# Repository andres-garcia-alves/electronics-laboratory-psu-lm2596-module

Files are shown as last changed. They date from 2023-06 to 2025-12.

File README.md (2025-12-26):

# Laboratory Power Supply Unit - LM2596 Module

Electronic adjustable laboratory power supply unit based on LM2596 DC-DC Step-Down module.  
Output 1.25-30V, max 2A, with current limitation feature.  

Based on videos (spanish):  
- [Control de Corriente para Fuente DC-DC LM2596](https://www.youtube.com/watch?v=ucfL-aOuTAA) from [KrissElectronics](https://www.youtube.com/@KrissElectronics) YouTube channel.
- [Fuente DC-DC LM2596, Control Externo Feedback](https://www.youtube.com/watch?v=mXjmIwHC1IA) from [Electgpl](https://www.youtube.com/@electgpl) YouTube channel.
- [Control de Corriente para DC-DC con LM2596, CC/CV con LM358](https://www.youtube.com/watch?v=a19zc0bWBYk) from [Electgpl](https://www.youtube.com/@electgpl) YouTube channel.

&nbsp;

This project use the following electronic components:
- 1 x LM2596 DC-DC Step-Down module (with current limitation).
- 1 x Voltimeter+Amperimeter DSN-VC288.
- 2 x Potenciometers B10K (lineal)
- 1 x Resistor 2.2ohm 15w.
- 2 x Borniers.
- 2 x 3 pins connectors.
- 1 x DC Jack female connector.

&nbsp;

### Screenshots

| Diagram - Schematics | Diagram - PCB |
|---|---|
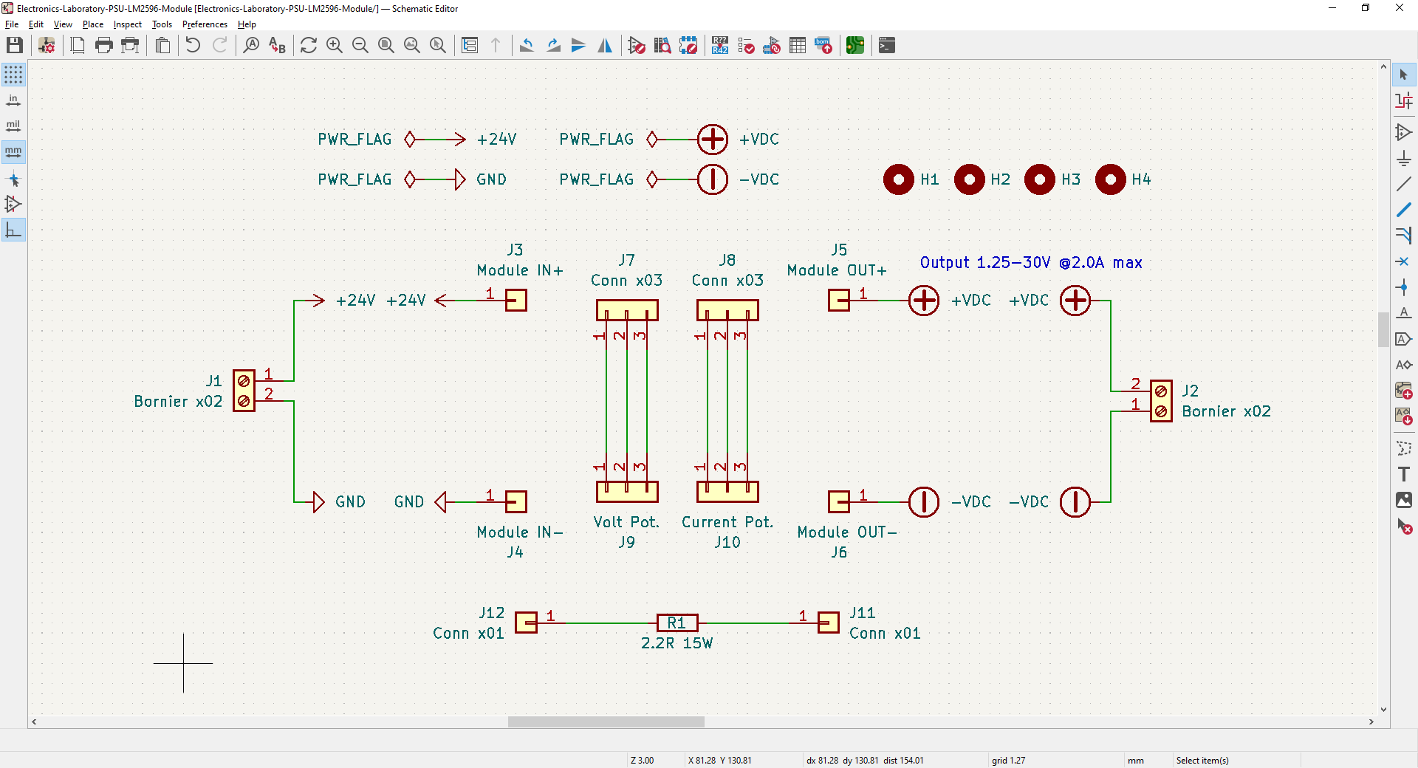
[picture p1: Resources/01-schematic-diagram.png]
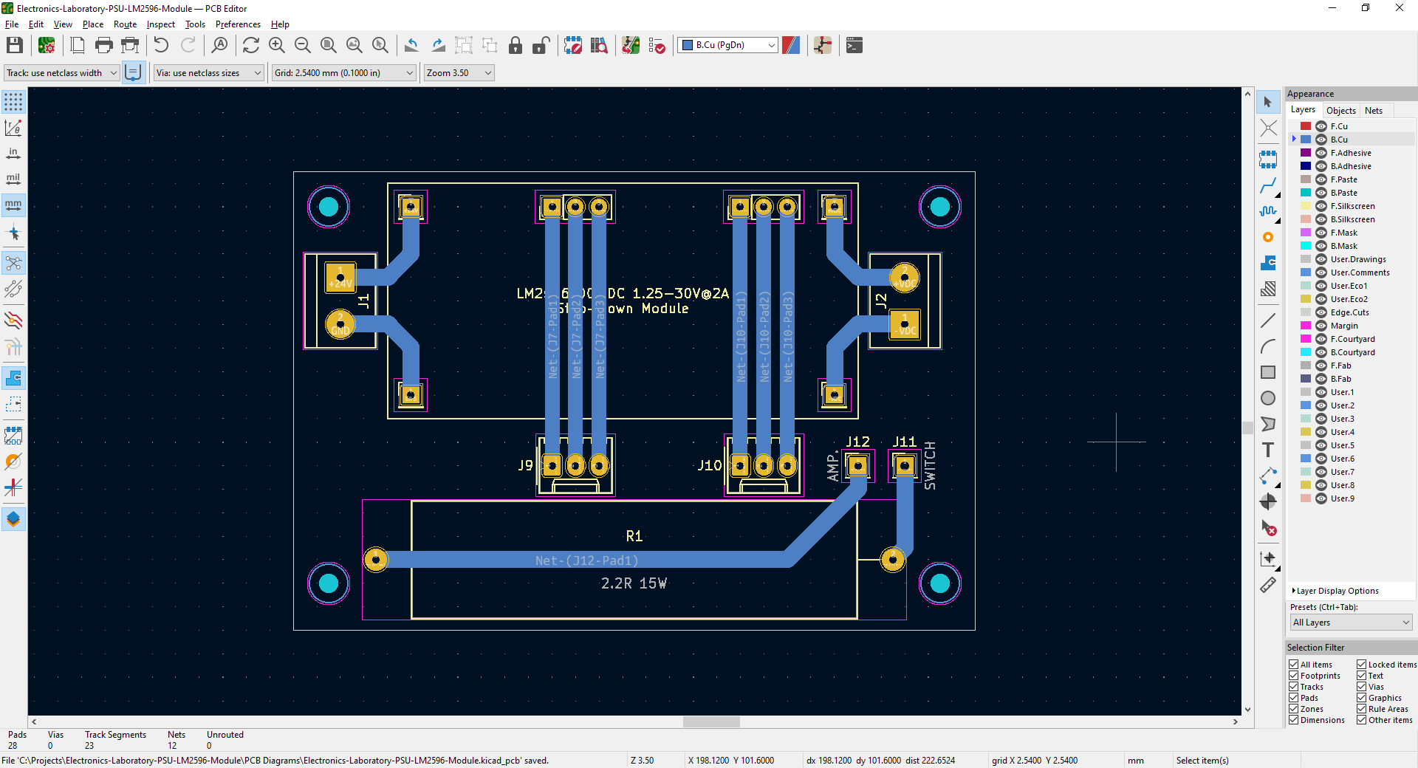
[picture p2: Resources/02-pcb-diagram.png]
|  |  |

| Diagram - PCB Render | Diagram - PCB Render |
|---|---|
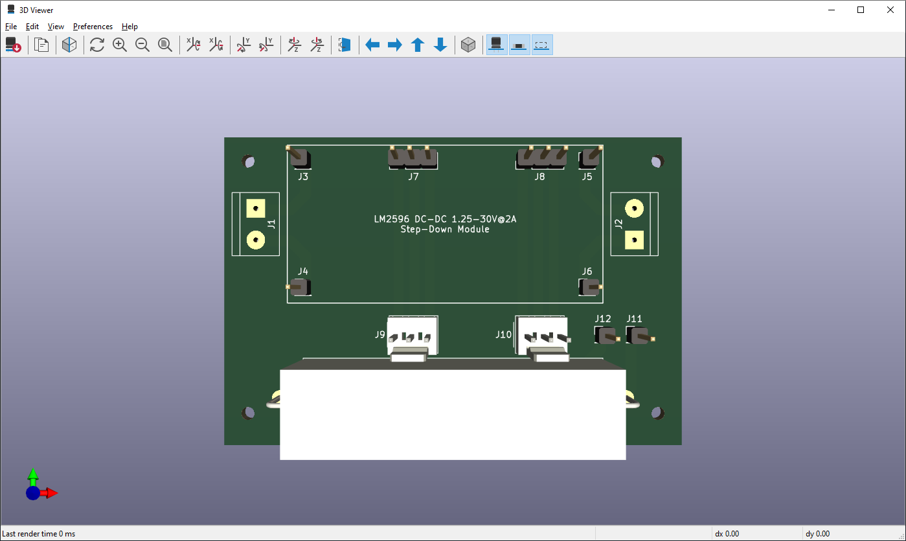
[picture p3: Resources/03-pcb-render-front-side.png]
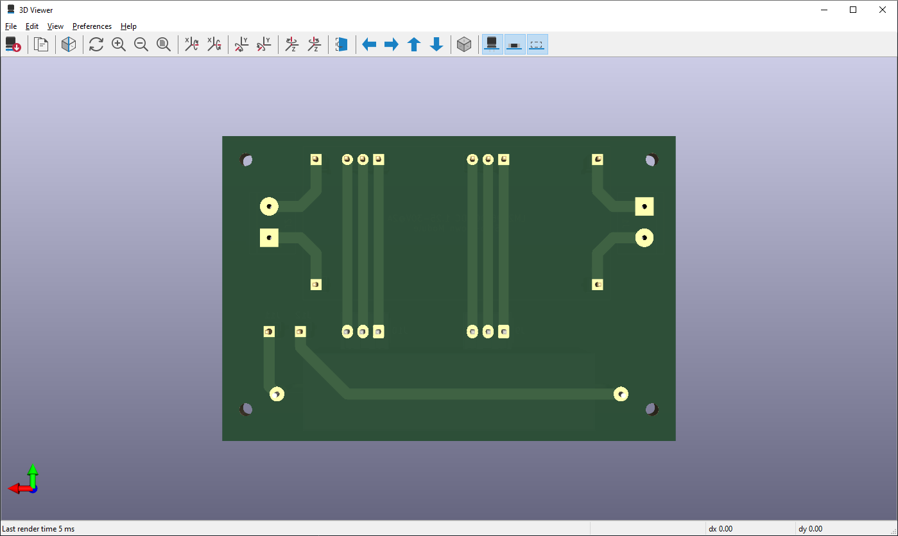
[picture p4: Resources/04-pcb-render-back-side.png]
|  |  |

| Diagram - Voltimeter/Amperimeter wiring | Diagram - Current control wiring |
|---|---|
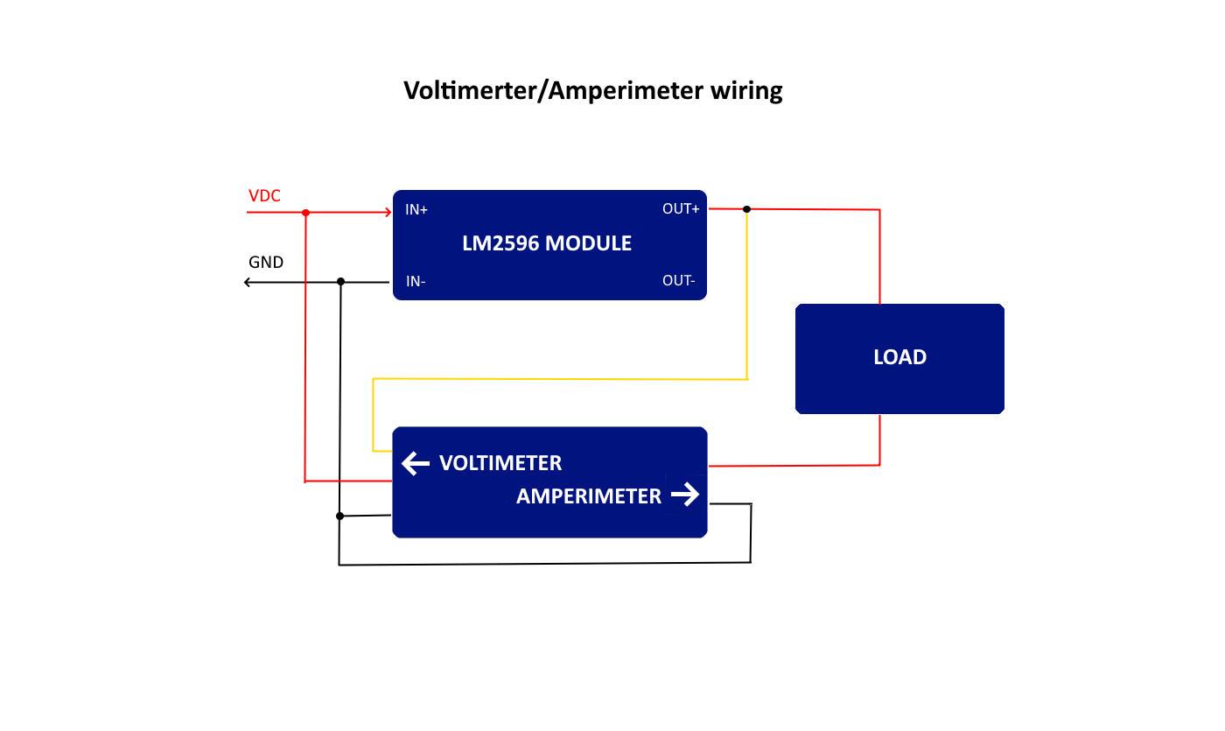
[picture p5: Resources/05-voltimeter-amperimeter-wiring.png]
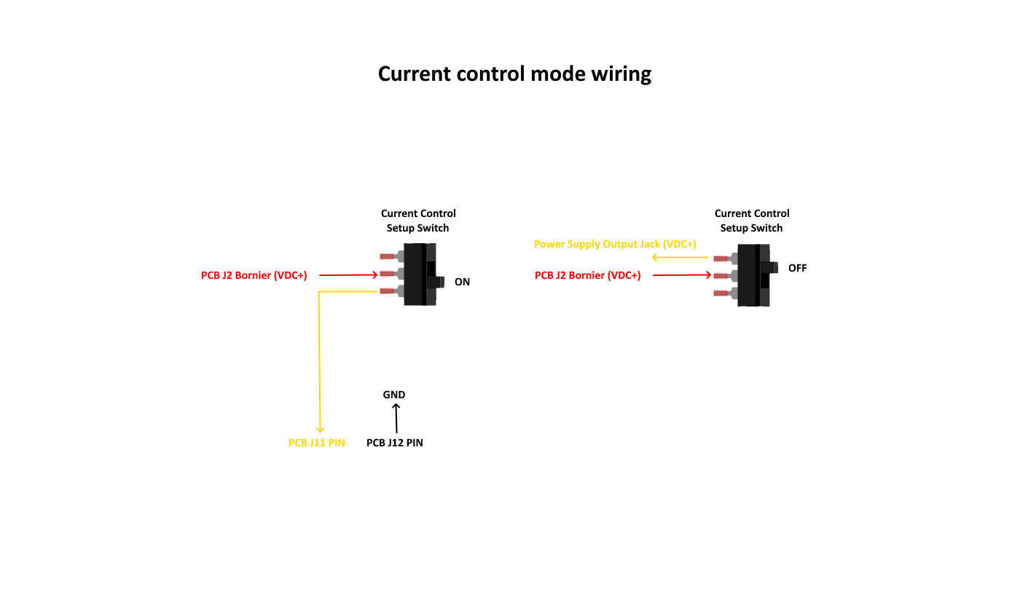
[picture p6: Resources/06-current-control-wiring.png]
|  |  |

| Case - 3D Model | Prototype |
|---|---|
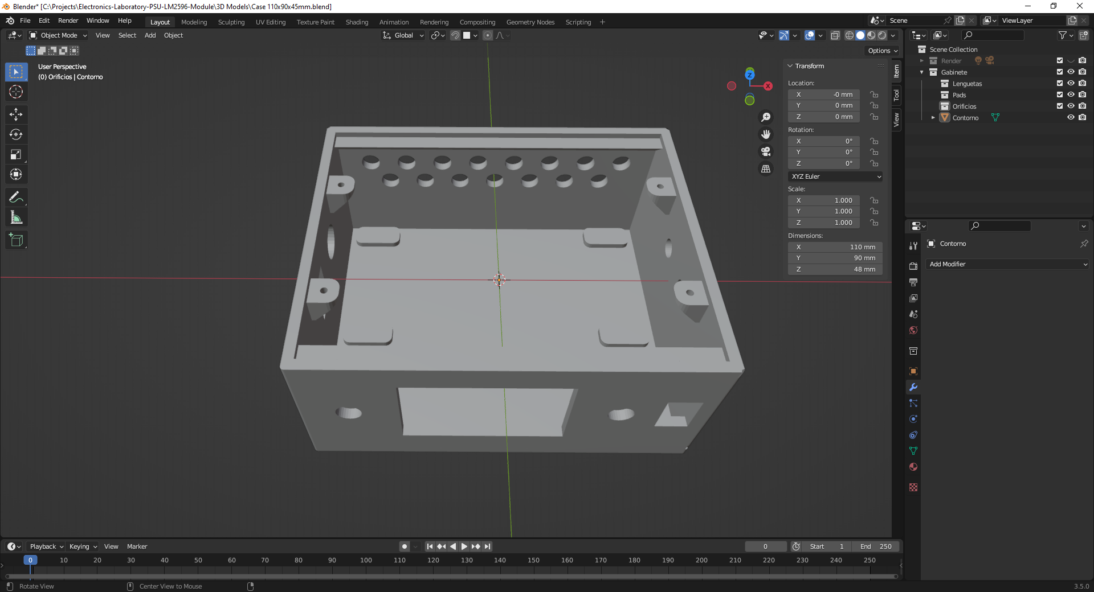
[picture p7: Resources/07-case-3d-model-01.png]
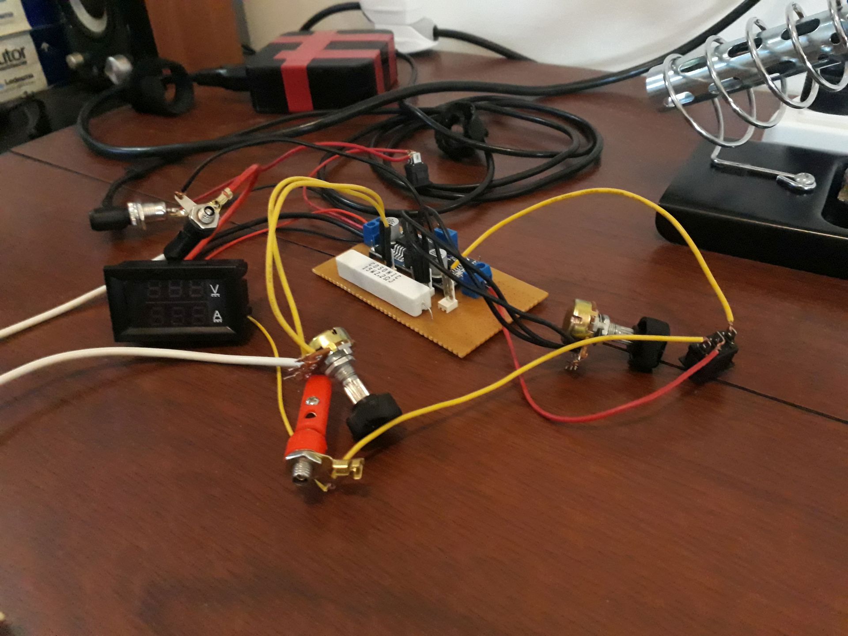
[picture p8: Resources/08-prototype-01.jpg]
|  |  |

| Project Assembly | Project Assembly |
|---|---|
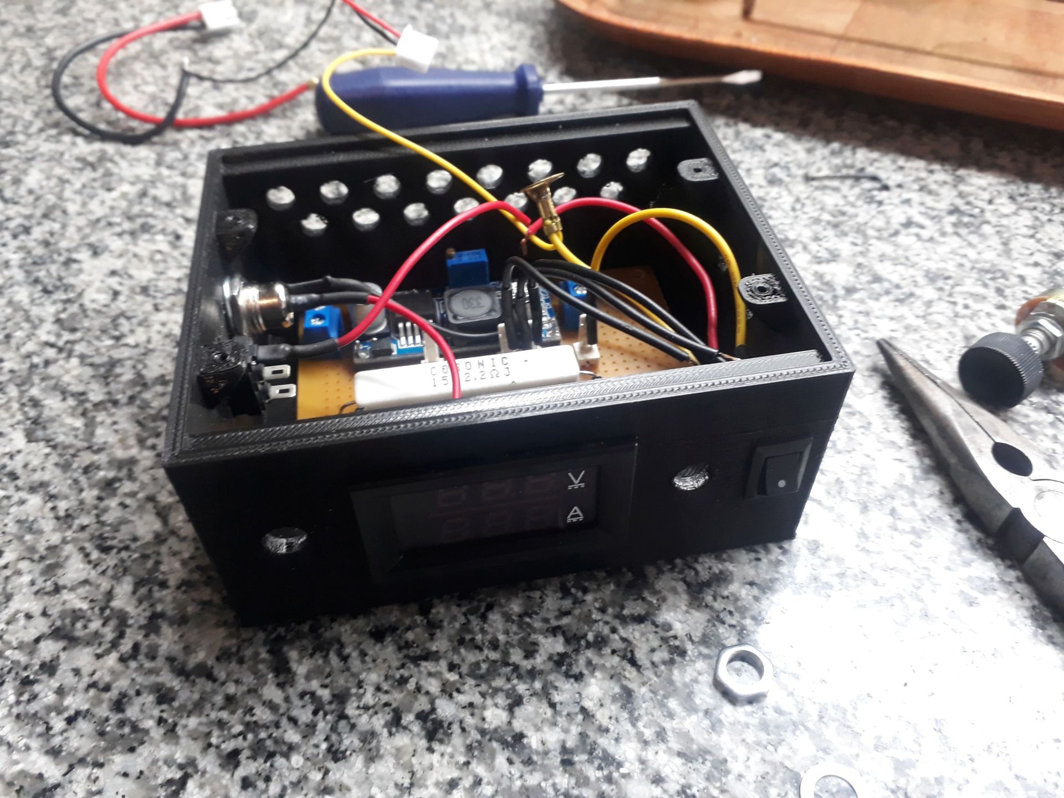
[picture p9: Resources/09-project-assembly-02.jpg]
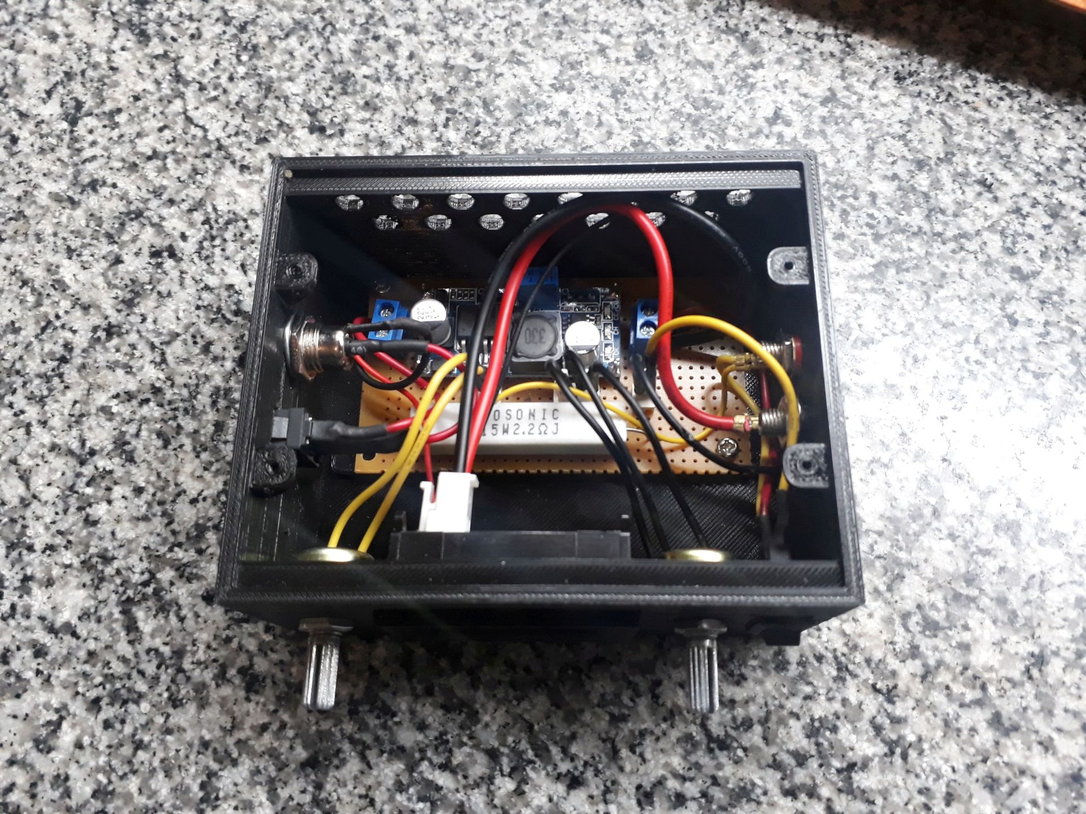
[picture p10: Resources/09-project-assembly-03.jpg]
|  |  |

| Project Final | Project Final |
|---|---|
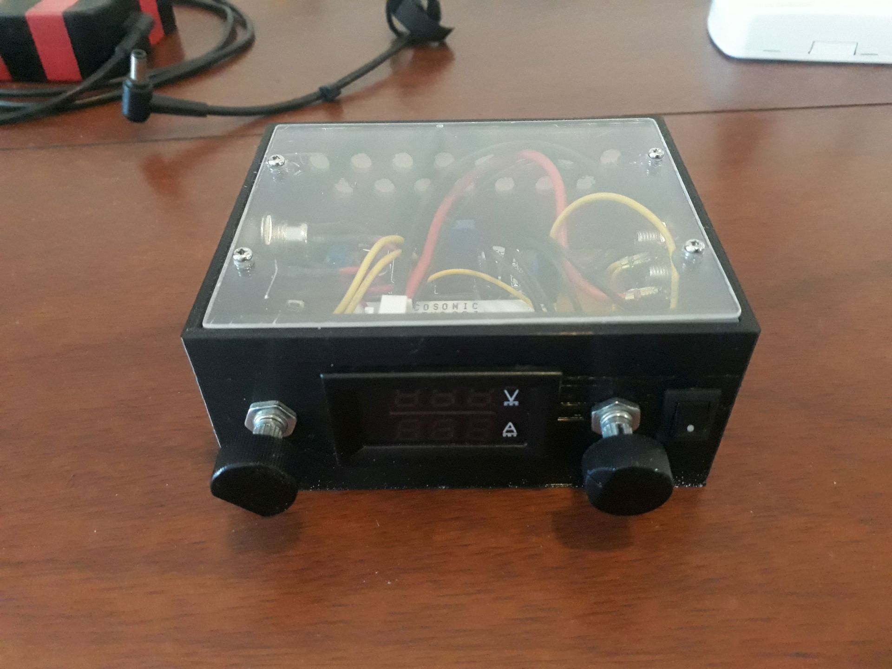
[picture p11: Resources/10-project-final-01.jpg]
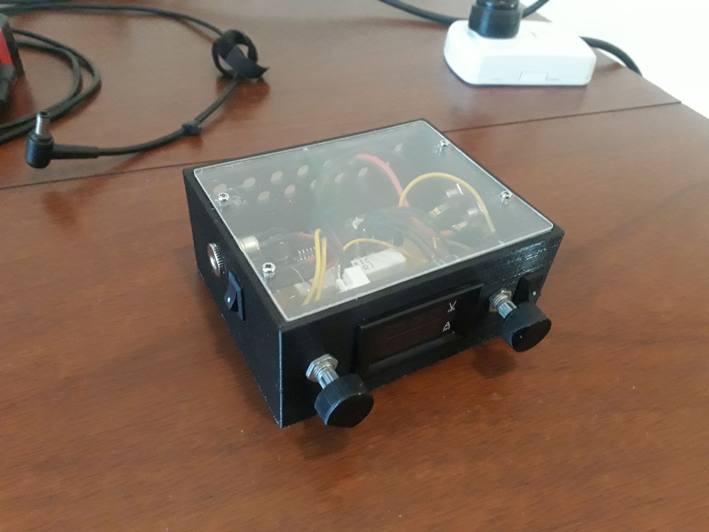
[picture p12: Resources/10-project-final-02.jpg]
|  |  |

| Project Final | Project Final (YouTube video) |
|---|---|
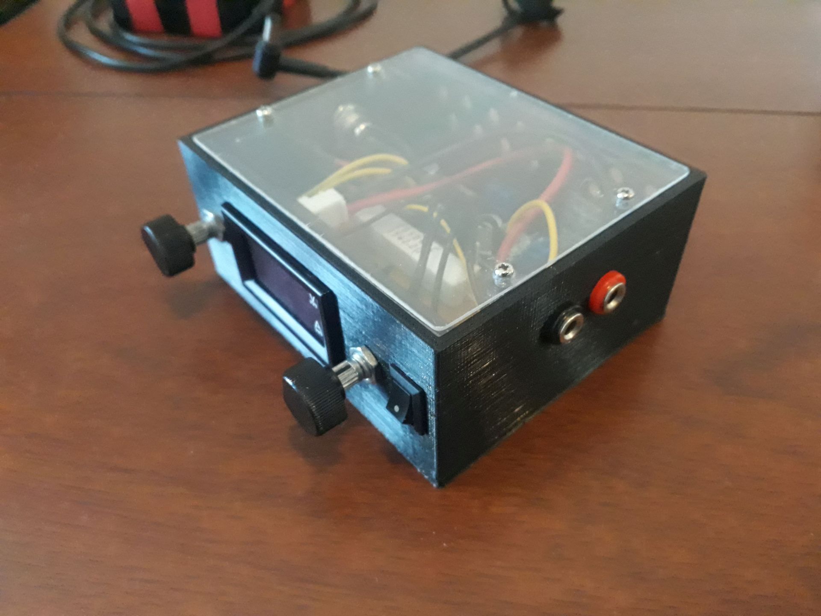
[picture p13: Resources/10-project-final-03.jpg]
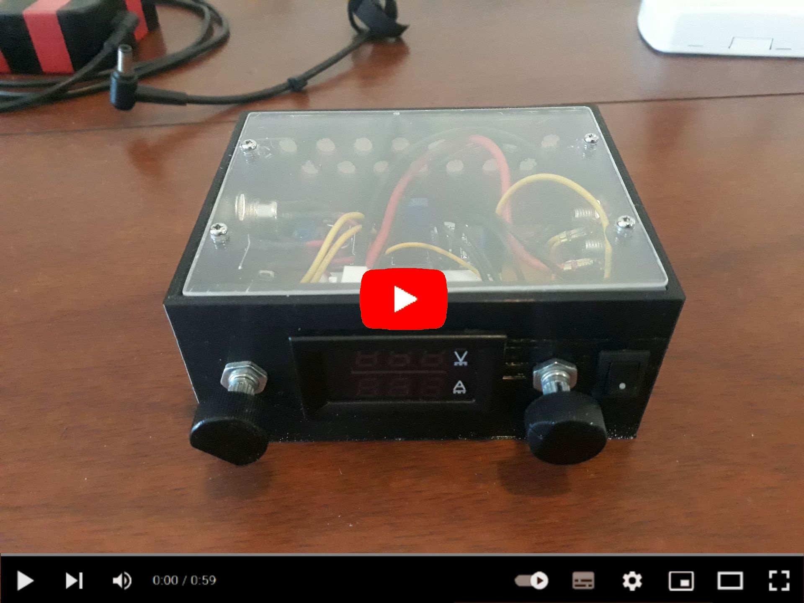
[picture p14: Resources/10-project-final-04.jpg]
(https://youtu.be/pehHUt3bOzo)
|  |  |

See 'Rescources' sub-folder for more pictures & videos of the project.

&nbsp;

### Version History

v1.0 (2023.06.07) - Initial release.  
v1.1 (2023.06.28) - Update electronic diagrams, adding case 3D model.  
v1.2 (2023.07.08) - Adding 'Resources' folder.  
v1.3 (2025.12.26) - Adding 'Stickers' folder.  

&nbsp;

This source code is licensed under GPL v3.0  
Please send me your feedback about this project: andres.garcia.alves@gmail.com

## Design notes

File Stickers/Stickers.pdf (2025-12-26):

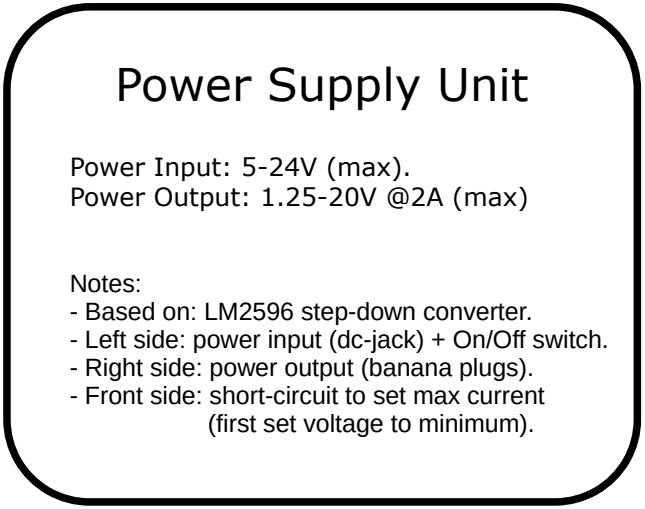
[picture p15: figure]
Power Supply Unit; Notes: - Based on: LM2596 step-down converter.; (first set voltage to minimum).; Power Input: 5-24V (max). Power Output: 1.25-20V @2A (max)

- Left side: power input (dc-jack) + On/Off switch.
- Right side: power output (banana plugs).
- Front side: short-circuit to set max current

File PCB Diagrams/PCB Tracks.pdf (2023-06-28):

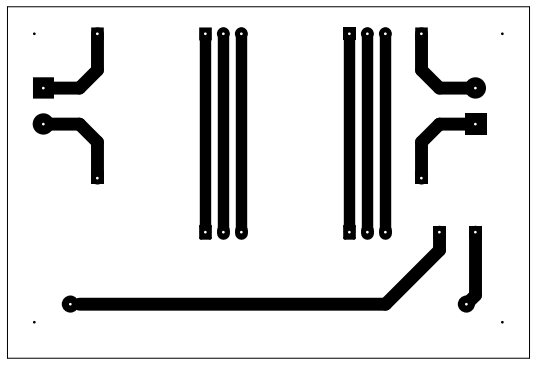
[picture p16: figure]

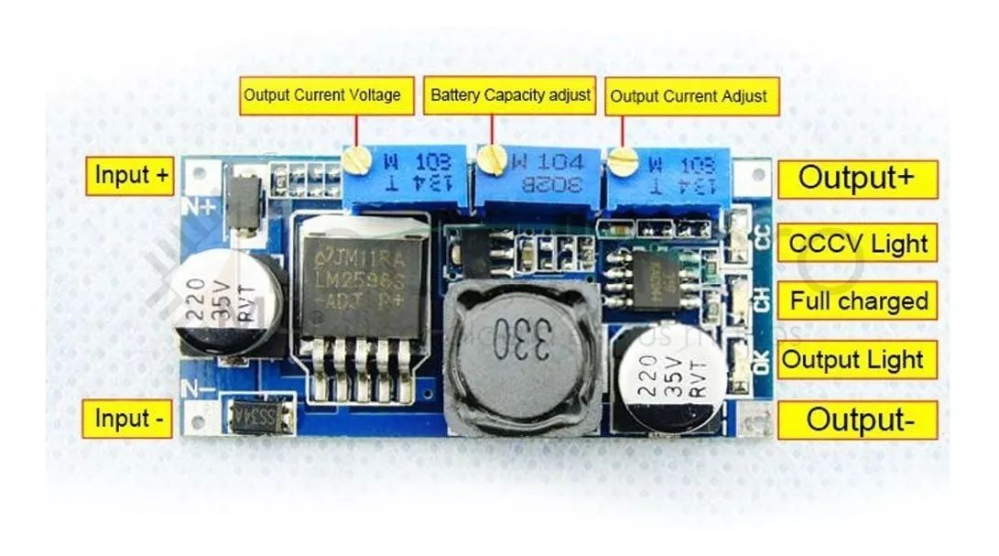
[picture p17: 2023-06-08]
Datasheets/Module LM2596-Adj-Current Specs 03.jpg

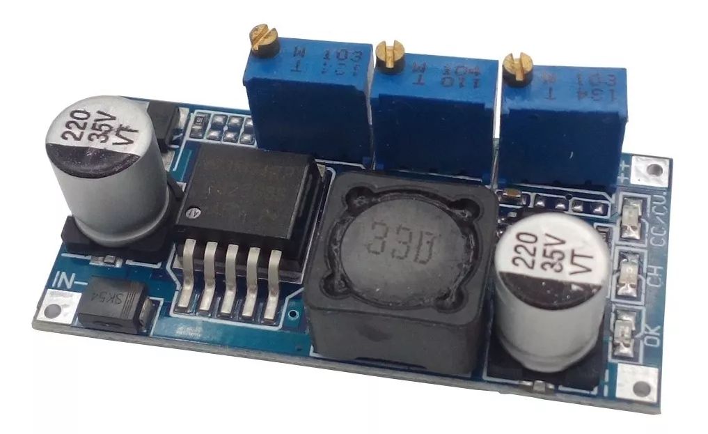
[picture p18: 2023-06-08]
Datasheets/Module LM2596-Adj-Current Specs 01.jpg

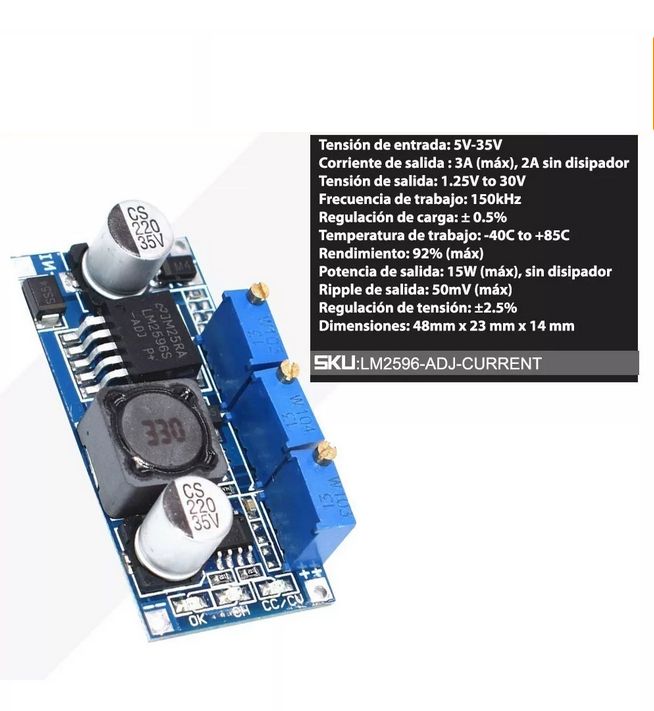
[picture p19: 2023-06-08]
Datasheets/Module LM2596-Adj-Current Specs 02.jpg

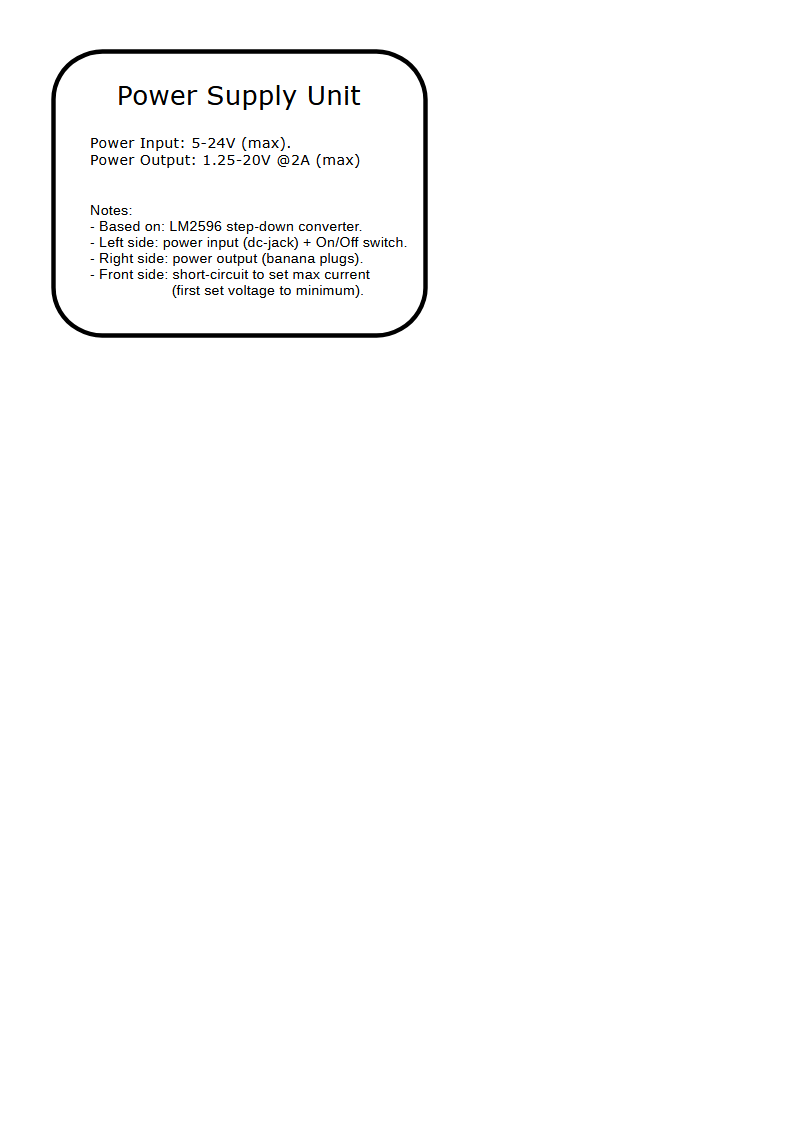
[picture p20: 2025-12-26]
Stickers/Stickers.png

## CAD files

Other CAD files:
3D Models/Case 110x90x45mm (without holes).blend
3D Models/Case 110x90x45mm.blend

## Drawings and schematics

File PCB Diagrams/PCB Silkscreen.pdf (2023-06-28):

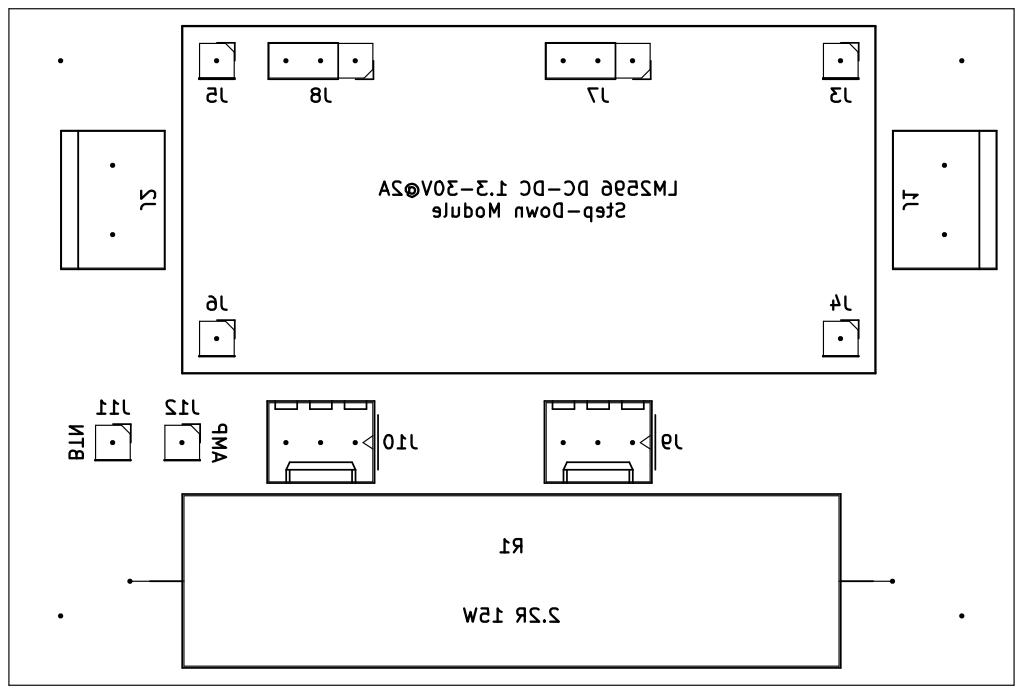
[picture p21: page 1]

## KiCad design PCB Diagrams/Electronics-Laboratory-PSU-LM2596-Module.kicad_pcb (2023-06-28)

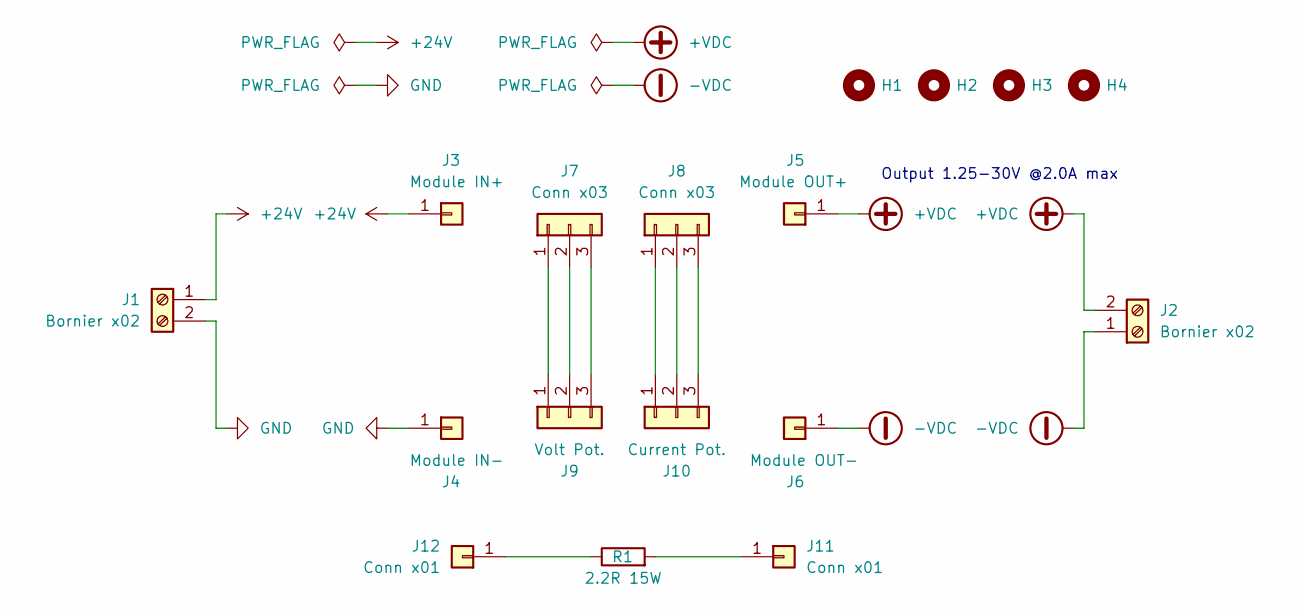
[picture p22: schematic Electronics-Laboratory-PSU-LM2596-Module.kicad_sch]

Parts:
H1, H2, H3, H4: MountingHole; MountingHole_2.1mm
J1, J2: Bornier x02; TerminalBlock_bornier-2_P5.08mm
J3: Module IN+; PinHeader_1x01_P2.54mm_Vertical
J4: Module IN-; PinHeader_1x01_P2.54mm_Vertical
J5: Module OUT+; PinHeader_1x01_P2.54mm_Vertical
J6: Module OUT-; PinHeader_1x01_P2.54mm_Vertical
J7, J8: Conn x03; PinHeader_1x03_P2.54mm_Vertical
J9: Volt Pot.; Molex_KK-254_AE-6410-03A_1x03_P2.54mm_Vertical
J10: Current Pot.; Molex_KK-254_AE-6410-03A_1x03_P2.54mm_Vertical
J11, J12: Conn x01; PinHeader_1x01_P2.54mm_Vertical
R1: 2.2R 15W; R_Axial_Power_L48.0mm_W12.5mm_P55.88mm

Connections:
+24V: J1.1, J3.1
+VDC: J2.2, J5.1
-VDC: J2.1, J6.1
GND: J1.2, J4.1
unnamed: J7.1, J9.1
unnamed: J7.2, J9.2
unnamed: J7.3, J9.3
unnamed: J8.1, J10.1
unnamed: J8.2, J10.2
unnamed: J8.3, J10.3
unnamed: J11.1, R1.2
unnamed: J12.1, R1.1

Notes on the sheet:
Output 1.25-30V @2.0A max

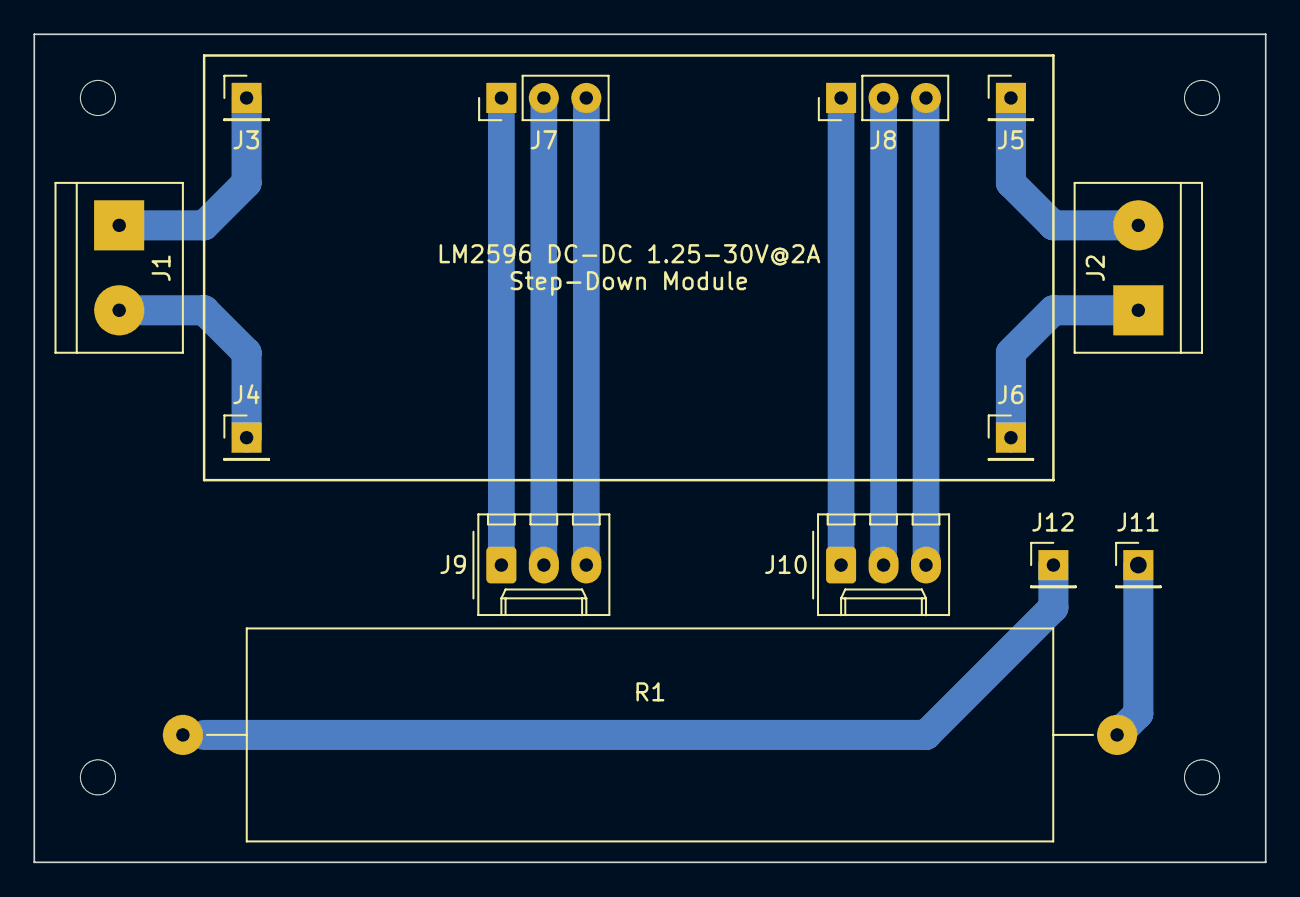
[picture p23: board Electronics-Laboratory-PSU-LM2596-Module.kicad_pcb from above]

Board: 2 copper layers, 73.7 x 49.5 mm, 17 parts (0 on the bottom side), 12 nets.

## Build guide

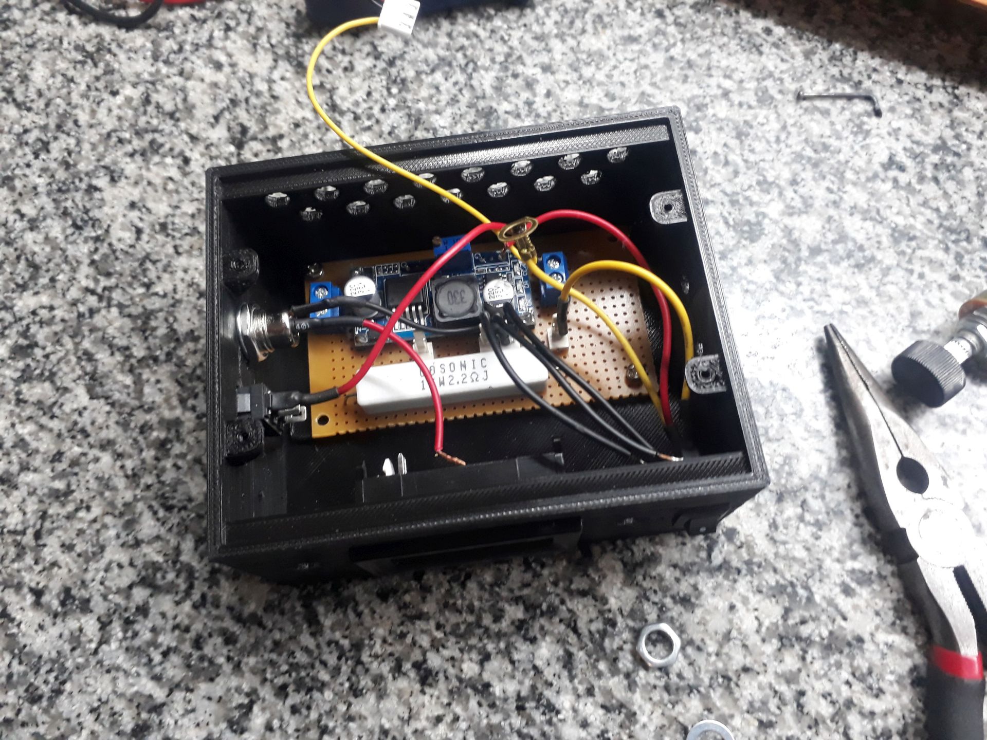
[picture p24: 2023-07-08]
Resources/09-project-assembly-01.jpg

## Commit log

2023-06-08 update PCB diagrams
    [Electronic-Laboratory-PSU-LM2596-IC.kicad_pcb, Electronic-Laboratory-PSU-LM2596-IC.kicad_sch, Electronic-Laboratory-PSU-LM2596-Module.kicad_pcb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]
2023-06-28 update electronic diagrams, adding case 3D model
    [Case 110x90x45mm (without holes).blend, Case 110x90x45mm.blend, Electronics-Laboratory-PSU-LM2596-Module.kicad_pcb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]
2023-06-28 update PCB diagrams, adding case 3D model
    [Case 110x90x45mm.blend]
